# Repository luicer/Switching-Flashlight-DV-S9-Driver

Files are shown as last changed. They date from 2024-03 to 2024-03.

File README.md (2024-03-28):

# Switching driver for diving flashlight  DV-S9
Design of an adjustable switching regulator driver for DV-S9 diving flashlight, supporting current up to 1 A and input voltage between 3V and 4.2V, along with low standby current. The driver achieves up to 85% efficiency at maximum current. This design is open source hardware.

Teaser

Post where the design is esplained:
[https://luicer.github.io/led%20flashlight/Flashlight-Driver-Switching-Eng/](https://luicer.github.io/led%20flashlight/Flashlight-Driver-Switching-Eng/)

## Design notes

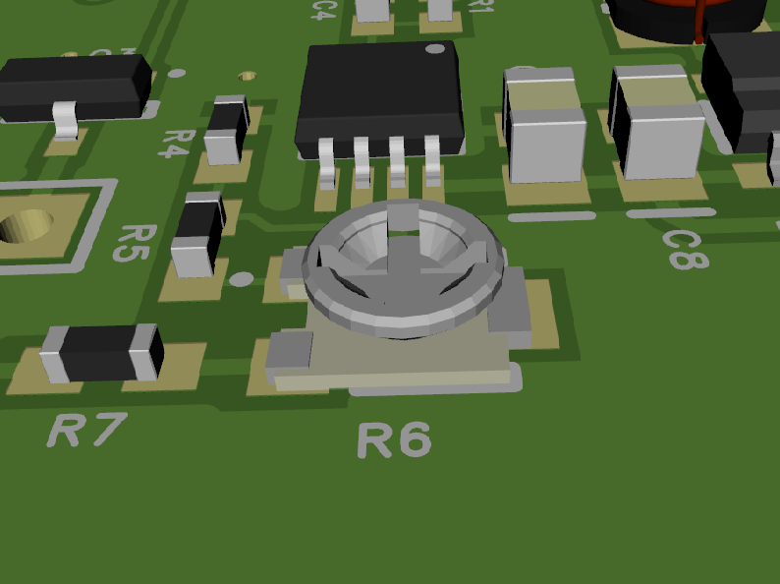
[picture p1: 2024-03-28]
KICAD/ul_TC33X-2-103E/3d/3303w-3_img.png

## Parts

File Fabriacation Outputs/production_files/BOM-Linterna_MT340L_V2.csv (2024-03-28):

Comment | Designator | Footprint | LCSC
15p | C5 | C_0805_2012Metric_Pad1.15x1.40mm_HandSolder | C107110
10u | C6 | C_0805_2012Metric_Pad1.18x1.45mm_HandSolder | C15850
10k | R5 | R_0805_2012Metric_Pad1.15x1.40mm_HandSolder | C17414
120k | R4 | R_0805_2012Metric_Pad1.15x1.40mm_HandSolder | C17436
200K | R3 | R_0805_2012Metric_Pad1.15x1.40mm_HandSolder | C17539
82k | R1 | R_0805_2012Metric_Pad1.15x1.40mm_HandSolder | C1755
HT7130 | U5 | SOT-89-3 | C19162
1u | C2 | C_0805_2012Metric_Pad1.15x1.40mm_HandSolder | C28323
MMBT3906 | Q1 | SOT-23 | C2910191
2.2u | L1 | CD43NP-100MC | C2926400
1n | C3 | C_0805_2012Metric_Pad1.15x1.40mm_HandSolder | C46653
100n | C8 | C_0805_2012Metric_Pad1.18x1.45mm_HandSolder | C49678
0.01 | R6 | R_2512_6332Metric_Pad1.52x3.35mm_HandSolder | C571497
10u | C1 | CP_EIA-3216-18_Kemet-A_Pad1.58x1.35mm_HandSolder | C7171
10K | RV1 | TC33X-2-103E | C719176
SGM8551XN | U3,U4 | SOT-23-5 | C83748
SS49E | U1 | SS49E | C85697
MT3410L | U2 | TSOT-23-5 | C883494
0 | R7 | R_0805_2012Metric_Pad1.15x1.40mm_HandSolder
nc | C4 | C_0805_2012Metric_Pad1.15x1.40mm_HandSolder
BAT- | J2 | Lin_Pad-
NC | R2 | R_0805_2012Metric_Pad1.15x1.40mm_HandSolder
BAT + | J1 | Lin_Pad+
nc | C7 | C_0805_2012Metric_Pad1.18x1.45mm_HandSolder

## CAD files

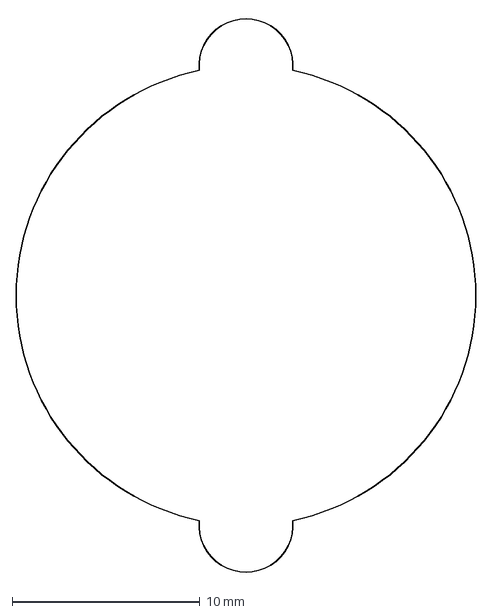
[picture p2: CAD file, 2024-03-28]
KICAD/Cut_edge1.dxf
24.5 x 29.8 mm

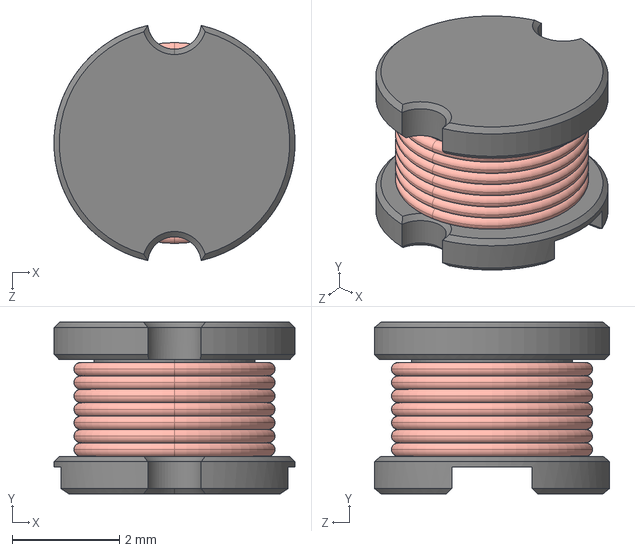
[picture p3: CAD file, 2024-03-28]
KICAD/ul_CD43NP-100MC/3d/CD43_inductor.STEP
4.49 x 3.20 x 4.39 mm

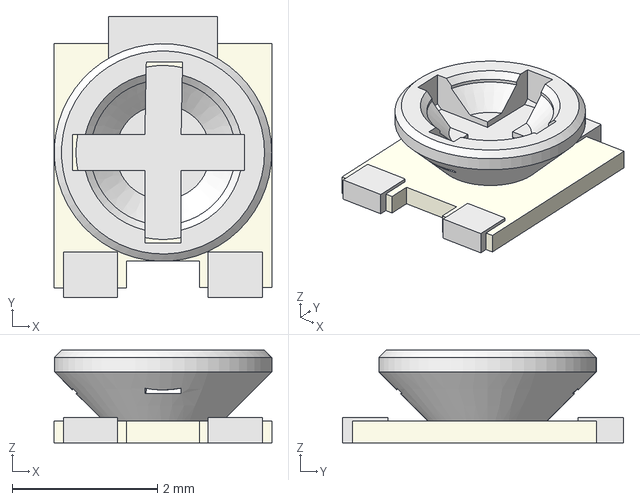
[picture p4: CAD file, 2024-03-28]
KICAD/ul_TC33X-2-103E/3d/3303W-3.step
3.00 x 3.88 x 1.28 mm

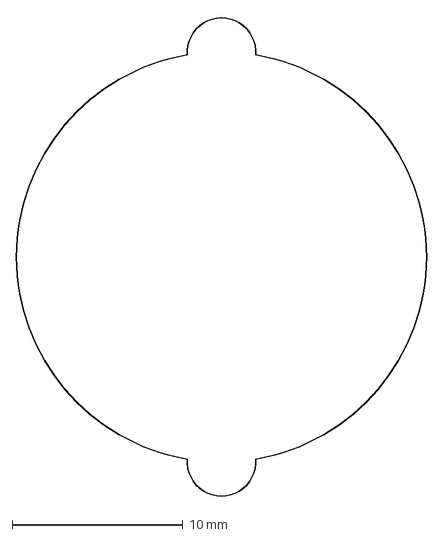
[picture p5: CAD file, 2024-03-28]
KICAD/Cut_edge.dxf
24.0 x 28.2 mm

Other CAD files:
KICAD/Cut_edge.dwg
KICAD/Cut_edge1.dwg
KICAD/ul_CD43NP-100MC/3d/CD43_inductor.SLDPRT

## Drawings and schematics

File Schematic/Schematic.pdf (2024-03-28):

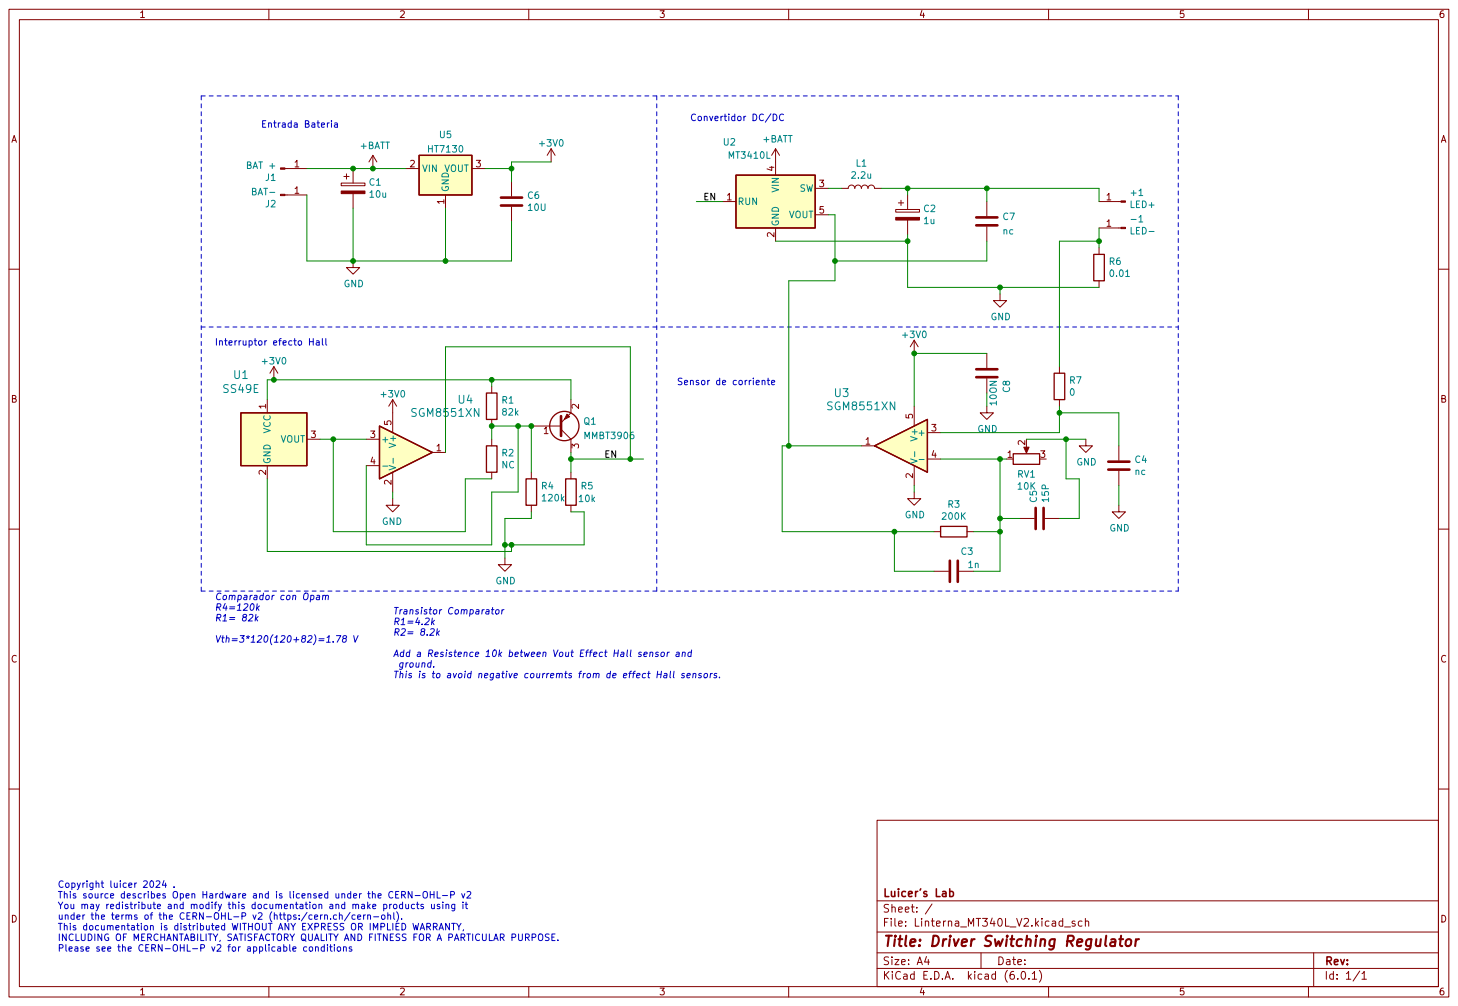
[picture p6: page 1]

Convertidor DC/DC Entrada Bateria

Transistor Comparator R1=4.2k R2= 8.2k Add a Resistence 10k between Vout Effect Hall sensor and

Copyright luicer 2024 .
This source describes Open Hardware and is licensed under the CERN-OHL-P v2
You may redistribute and modify this documentation and make products using it
under the terms of the CERN-OHL-P v2 (https:/cern.ch/cern-ohl). This documentation is distributed WITHOUT ANY EXPRESS OR IMPLIED WARRANTY,

File: Linterna_MT340L_V2.kicad_sch Sheet: / Luicer's Lab

Id: 1/1 Title: Driver Switching Regulator

INCLUDING OF MERCHANTABILITY, SATISFACTORY QUALITY AND FITNESS FOR A PARTICULAR PURPOSE. Please see the CERN-OHL-P v2 for applicable conditions

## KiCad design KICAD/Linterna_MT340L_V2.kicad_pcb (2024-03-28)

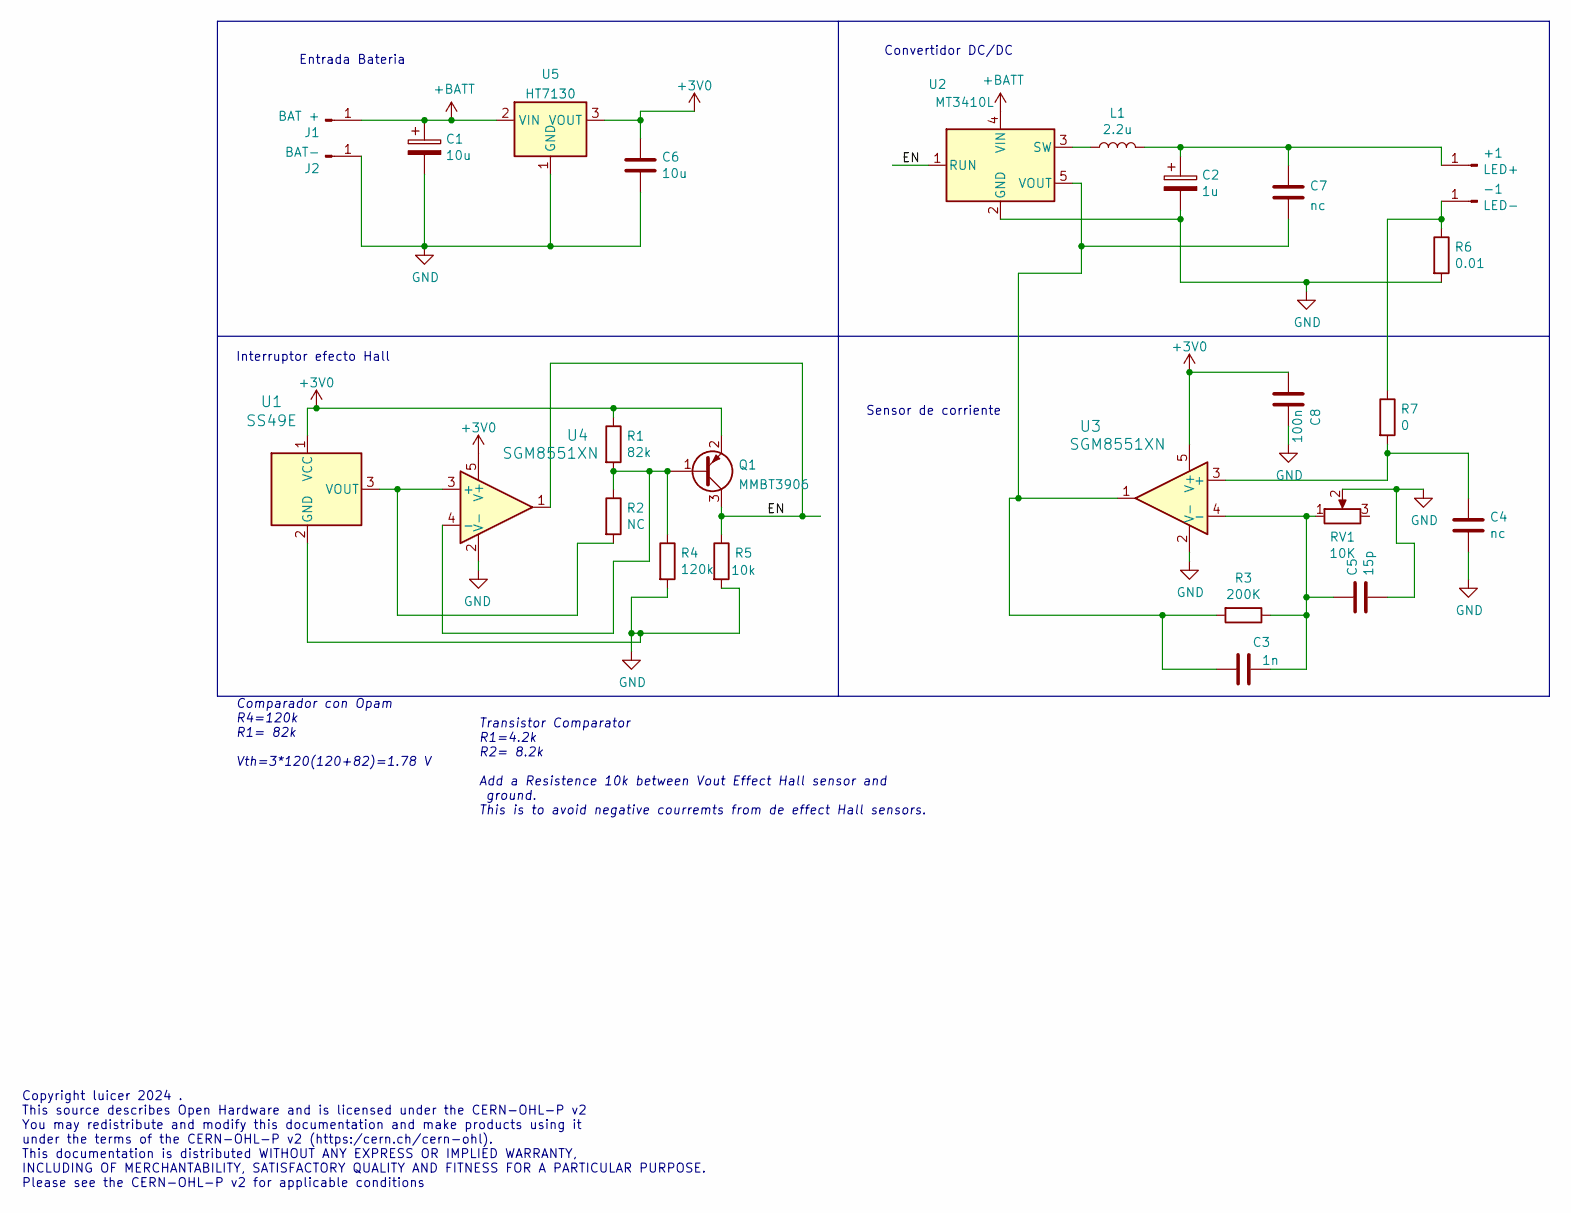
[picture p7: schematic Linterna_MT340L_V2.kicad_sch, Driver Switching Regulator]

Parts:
+1: LED+; Solder_Pad3_3
-1: LED-; Solder_Pad3_3
C1: 10u; CP_EIA-3216-18_Kemet-A_Pad1.58x1.35mm_HandSolder
C2: 1u; C_0805_2012Metric_Pad1.15x1.40mm_HandSolder
C3: 1n; C_0805_2012Metric_Pad1.15x1.40mm_HandSolder
C4: nc; C_0805_2012Metric_Pad1.15x1.40mm_HandSolder
C5: 15p; C_0805_2012Metric_Pad1.15x1.40mm_HandSolder
C6: 10u; C_0805_2012Metric_Pad1.18x1.45mm_HandSolder
C7: nc; C_0805_2012Metric_Pad1.18x1.45mm_HandSolder
C8: 100n; C_0805_2012Metric_Pad1.18x1.45mm_HandSolder
J1: BAT +; Lin_Pad+
J2: BAT-; Lin_Pad-
L1: 2.2u; CD43NP-100MC
Q1: MMBT3906; SOT-23
R1: 82k; R_0805_2012Metric_Pad1.15x1.40mm_HandSolder
R2: NC; R_0805_2012Metric_Pad1.15x1.40mm_HandSolder
R3: 200K; R_0805_2012Metric_Pad1.15x1.40mm_HandSolder
R4: 120k; R_0805_2012Metric_Pad1.15x1.40mm_HandSolder
R5: 10k; R_0805_2012Metric_Pad1.15x1.40mm_HandSolder
R6: 0.01; R_2512_6332Metric_Pad1.52x3.35mm_HandSolder
R7: 0; R_0805_2012Metric_Pad1.15x1.40mm_HandSolder
RV1: 10K; TC33X-2-103E
U1: SS49E
U2: MT3410L; TSOT-23-5
U3, U4: SGM8551XN; SOT-23-5
U5: HT7130; SOT-89-3

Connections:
+3V0: C6.1, C8.2, Q1.2 (E), R1.1, U1.1 (VCC), U3.5 (V+), U4.5 (V+), U5.3 (VOUT)
+BATT: C1.1, J1.1, U2.4 (VIN), U5.2 (VIN)
/EN: Q1.3 (C), R5.1, U2.1 (RUN), U4.1
GND: C1.2, C2.2, C4.2, C5.2, C6.2, C8.1, J2.1, R4.2, R5.2, R6.2, RV1.2, U1.2 (GND), U2.2 (GND), U3.2 (V-), U4.2 (V-), U5.1 (GND)
unnamed: +1.1, C2.1, C7.1, L1.2
unnamed: -1.1, R6.1, R7.1
unnamed: C3.1, C5.1, R3.1, RV1.1, U3.4 (-)
unnamed: C3.2, C7.2, R3.2, U2.5 (VOUT), U3.1
unnamed: C4.1, R7.2, U3.3 (+)
unnamed: L1.1, U2.3 (SW)
unnamed: Q1.1 (B), R1.2, R2.1, R4.1, U4.4 (-)
unnamed: R2.2, U1.3 (VOUT), U4.3 (+)

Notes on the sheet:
Transistor Comparator R1=4.2k R2= 8.2k Add a Resistence 10k between Vout Effect Hall sensor and ground. This is to avoid negative courremts from de effect Hall sensors.
Copyright luicer 2024 . This source describes Open Hardware and is licensed under the CERN-OHL-P v2 You may redistribute and modify this documentation and make products using it under the terms of the CERN-OHL-P v2 (https:/cern.ch/cern-ohl). This documentation is distributed WITHOUT ANY EXPRESS OR 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
Convertidor DC/DC
Entrada Bateria
Interruptor efecto Hall
Sensor de corriente
Comparador con Opam R4=120k R1= 82k Vth=3*120(120+82)=1.78 V

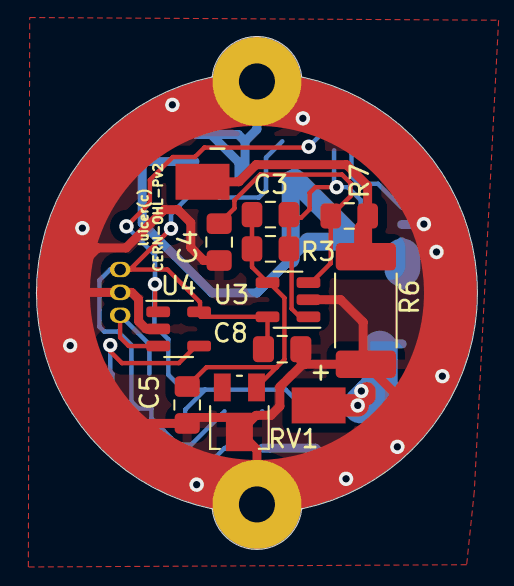
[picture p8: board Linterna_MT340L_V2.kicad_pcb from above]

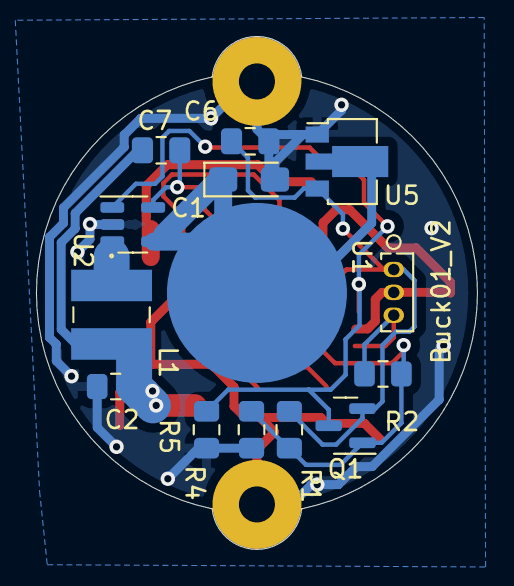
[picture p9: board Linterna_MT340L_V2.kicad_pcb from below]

Board: 2 copper layers, 24.5 x 28.5 mm, 27 parts (14 on the bottom side), 12 nets.

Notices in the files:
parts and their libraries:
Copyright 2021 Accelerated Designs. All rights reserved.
